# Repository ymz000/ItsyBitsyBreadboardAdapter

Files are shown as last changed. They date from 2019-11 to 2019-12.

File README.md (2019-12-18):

### _A stacking breadboard adapter for the ItsyBitsy M4 Express_

# ItsyBitsyBreadboardAdapter

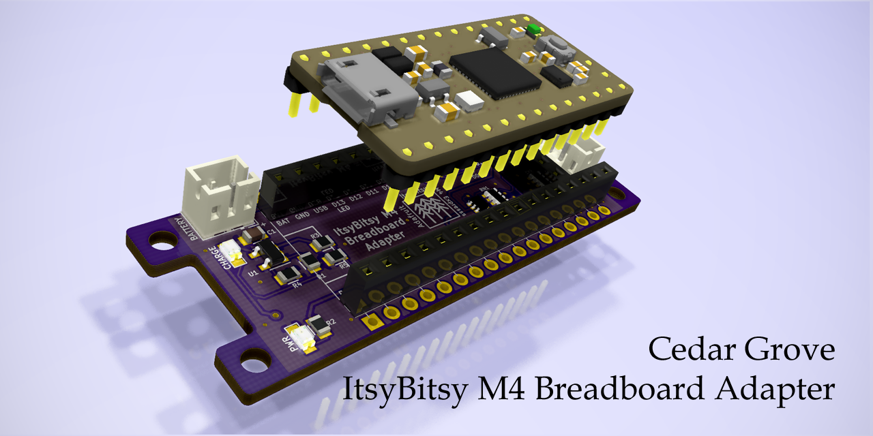
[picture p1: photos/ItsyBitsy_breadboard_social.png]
Image of Module


## Overview
The ItsyBitsy Breadboard Adapter is an Adafruit ItsyBitsy M4 Express-compatible piggyback module that converts the 3-sided pinout of the ItsyBitsy to dual in-line for use on typical solderless breadboards and soldered protoboards. The adapter was also designed with extra solderable pin connections and mounting ears for permanent installation.

Included is a level-shifted 4-pin JST STEMMA connector with jumper-selectable 5v or 3.3v power. The STEMMA interface can be configured to connect to the ItsyBitsy's UART (RX/TX) or I2C (SCL/SDA) signals. A 2-pin JST LiPo battery connection is on-board that supports charging (100mA charge rate), compatible with Adafruit's standard battery polarity.

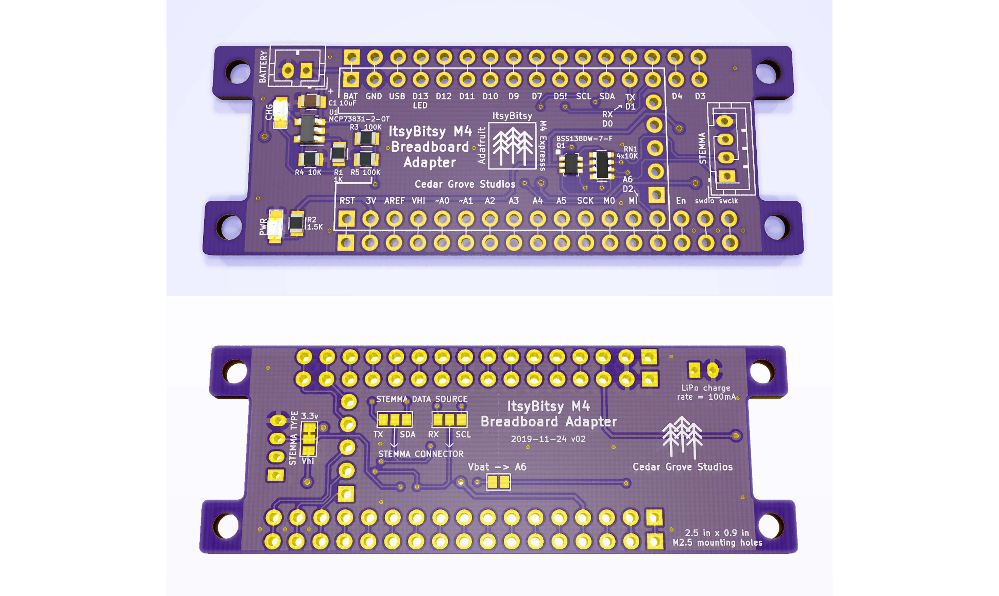
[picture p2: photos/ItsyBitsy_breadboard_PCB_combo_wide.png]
Image of PCB


OSH Park shared project:

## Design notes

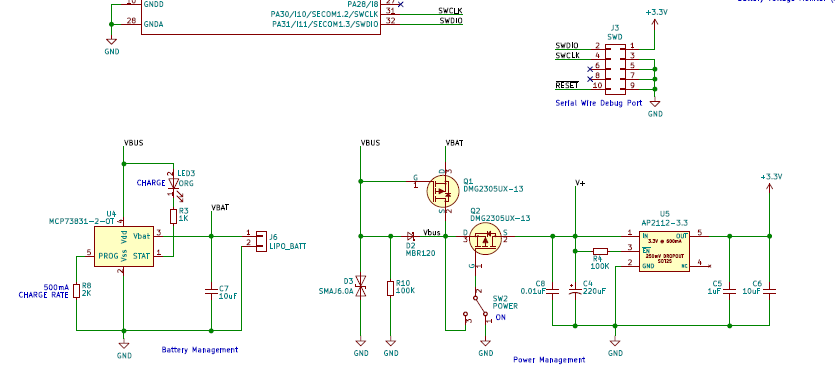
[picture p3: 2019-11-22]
photos/stringcar m0 pwr batt swd mgt.png

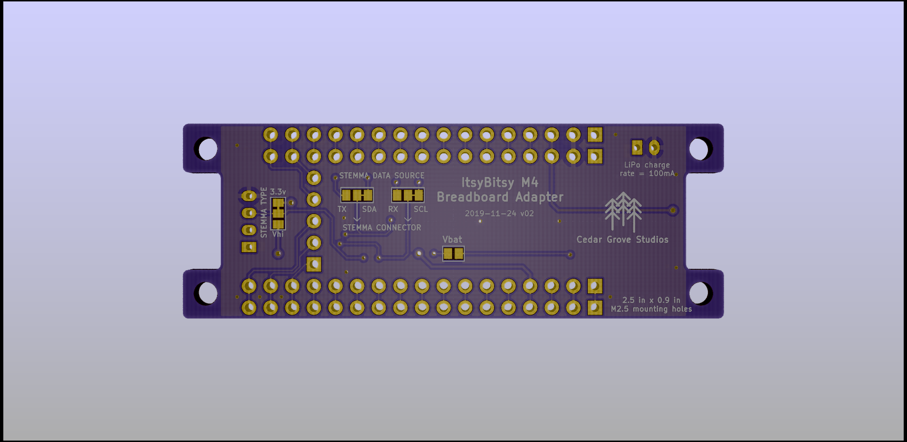
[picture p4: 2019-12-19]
photos/ItsyBitsy_breadboard_bot.png

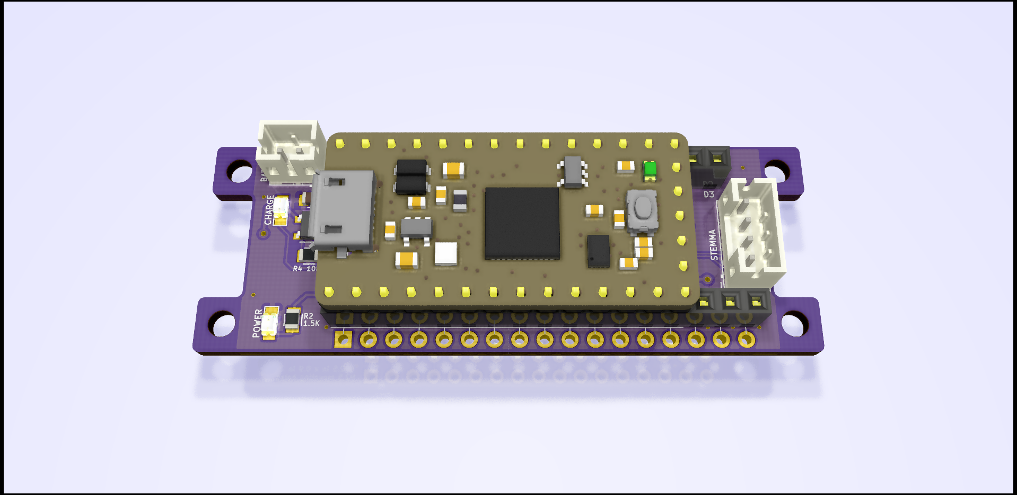
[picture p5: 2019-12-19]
photos/ItsyBitsy_breadboard_stacked.png

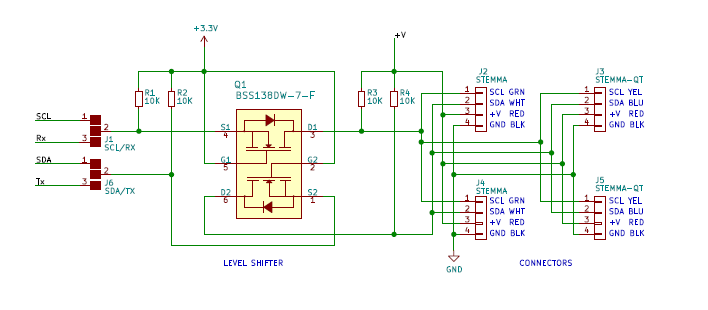
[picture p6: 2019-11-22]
photos/i2c buffer.png

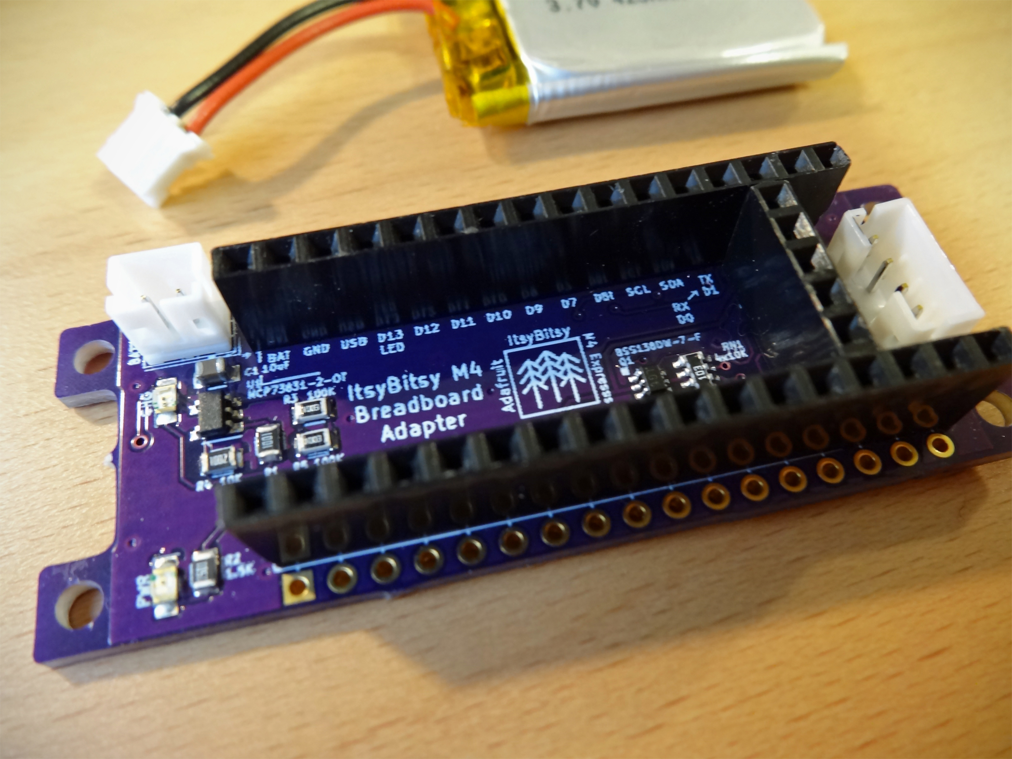
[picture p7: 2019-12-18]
photos/DSC05937a.jpg

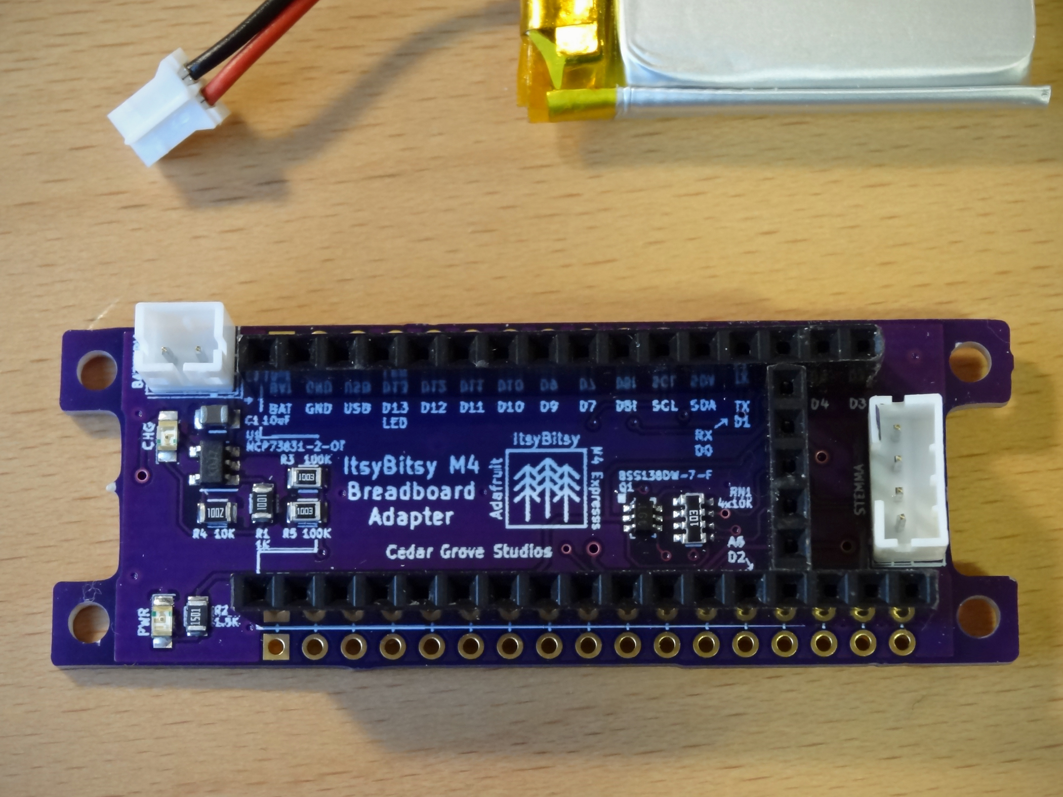
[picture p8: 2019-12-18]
photos/DSC05936a.jpg

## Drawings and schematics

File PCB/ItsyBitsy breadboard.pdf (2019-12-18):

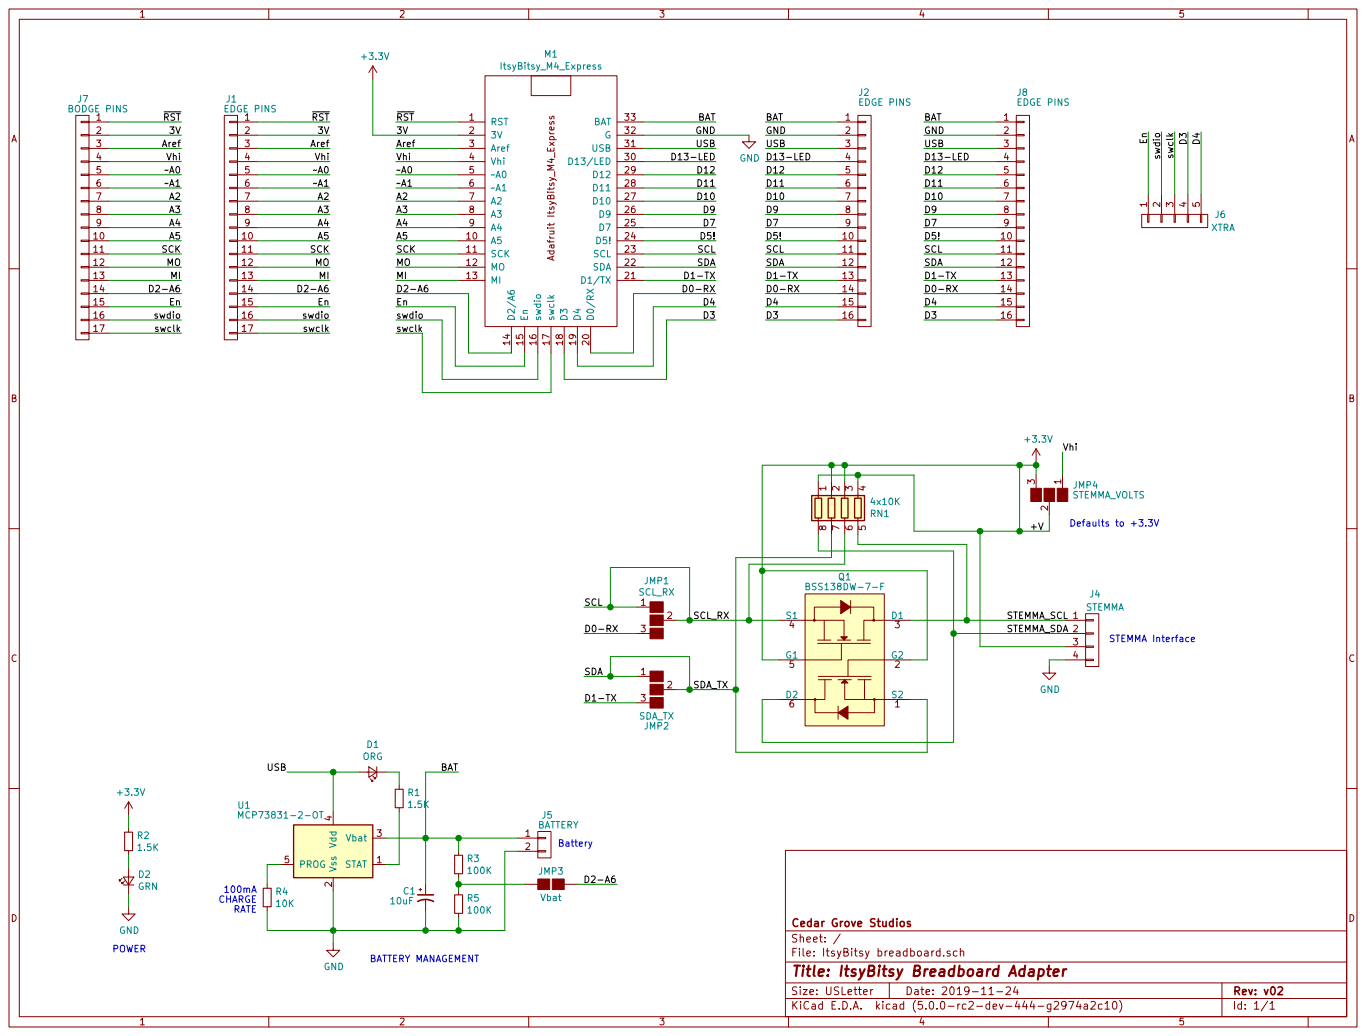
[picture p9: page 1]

File: ItsyBitsy breadboard.sch Sheet: / Cedar Grove Studios

Id: 1/1 Title: ItsyBitsy Breadboard Adapter

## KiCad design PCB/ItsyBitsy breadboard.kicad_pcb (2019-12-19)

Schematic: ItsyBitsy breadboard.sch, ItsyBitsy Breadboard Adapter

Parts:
C1: 10uF; C_0805
D1: ORG; LED_0805
D2: GRN; LED_0805
J1: EDGE PINS; Pin_Header_Straight_1x17_Pitch2.54mm_no_silk
J2, J8: EDGE PINS; Pin_Header_Straight_1x16_Pitch2.54mm_no_silk
J4: STEMMA; JST_PH_B4B-PH-K_04x2.00mm_Straight
J5: BATTERY; JST_PH_B2B-PH-K_02x2.00mm_Straight
J6: XTRA; Pin_Header_Straight_1x05_Pitch2.54mm_no_silk
J7: BODGE PINS; Pin_Header_Straight_1x17_Pitch2.54mm_no_silk
JMP1: SCL_RX; GS3
JMP2: SDA_TX; GS3
JMP3: Vbat; GS2
JMP4: STEMMA_VOLTS; GS3
M1: ItsyBitsy_M4_Express
Q1: BSS138DW-7-F; SOT-363; MPN BSS138DW-7-F; Digi-Key_PN BSS138DW-FDICT-ND
R1, R2: 1.5K; R_0805
R3, R5: 100K; R_0805
R4: 10K; R_0805
RN1: 4x10K; R_Array_Convex_4x0603
U1: MCP73831-2-OT; SOT-23-5

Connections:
+3V3: J1.2, J4.3, J7.2, JMP4.2, JMP4.3, Q1.2, Q1.5, R2.1, RN1.1, RN1.2, RN1.3, RN1.4
/A2: J1.7, J7.7
/A3: J1.8, J7.8
/A4: J1.9, J7.9
/A5: J1.10, J7.10
/Aref: J1.3, J7.3
/BAT: C1.1, J2.1, J5.1, J8.1, R3.1, U1.3 (Vbat)
/D0-RX: J2.14, J8.14, JMP1.3
/D1-TX: J2.13, J8.13, JMP2.3
/D2-A6: J1.14, J7.14, JMP3.1
/D3: J2.16, J6.4, J8.16
/D4: J2.15, J6.5, J8.15
/D5!: J2.10, J8.10
/D7: J2.9, J8.9
/D9: J2.8, J8.8
/D10: J2.7, J8.7
/D11: J2.6, J8.6
/D12: J2.5, J8.5
/D13-LED: J2.4, J8.4
/En: J1.15, J6.1, J7.15
/MI: J1.13, J7.13
/MO: J1.12, J7.12
/SCK: J1.11, J7.11
/SCL: J2.11, J8.11, JMP1.1, JMP1.2, Q1.4, RN1.6
/SDA: J2.12, J8.12, JMP2.1, JMP2.2, Q1.1, RN1.7
/STEMMA_SCL: J4.1, Q1.3, RN1.5
/STEMMA_SDA: J4.2, Q1.6, RN1.8
/USB: D1.2, J2.3, J8.3, U1.4 (Vdd)
/Vhi: J1.4, J7.4, JMP4.1
/swclk: J1.17, J6.3, J7.17
/swdio: J1.16, J6.2, J7.16
/~RST: J1.1, J7.1
/~~A0: J1.5, J7.5
/~~A1: J1.6, J7.6
GND: C1.2, D2.1, J2.2, J4.4, J5.2, J8.2, R4.2, R5.2, U1.2 (Vss)
unnamed: D1.1, R1.1
unnamed: D2.2, R2.2
unnamed: JMP3.2, R3.2, R5.1
unnamed: R1.2, U1.1 (STAT)
unnamed: R4.1, U1.5 (PROG)

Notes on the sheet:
STEMMA Interface
Battery
100mA CHARGE RATE
POWER
BATTERY MANAGEMENT
Defaults to +3.3V

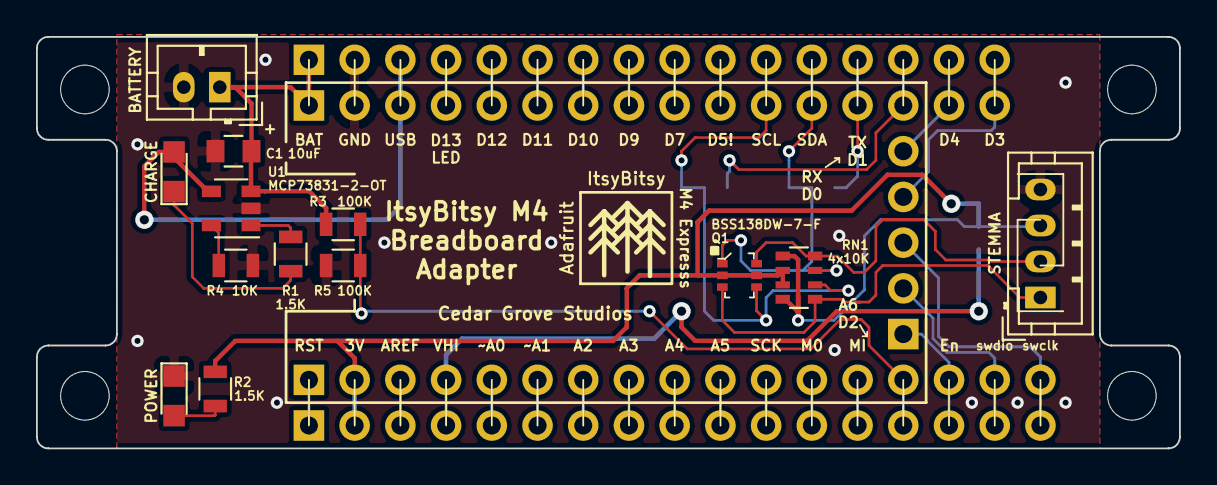
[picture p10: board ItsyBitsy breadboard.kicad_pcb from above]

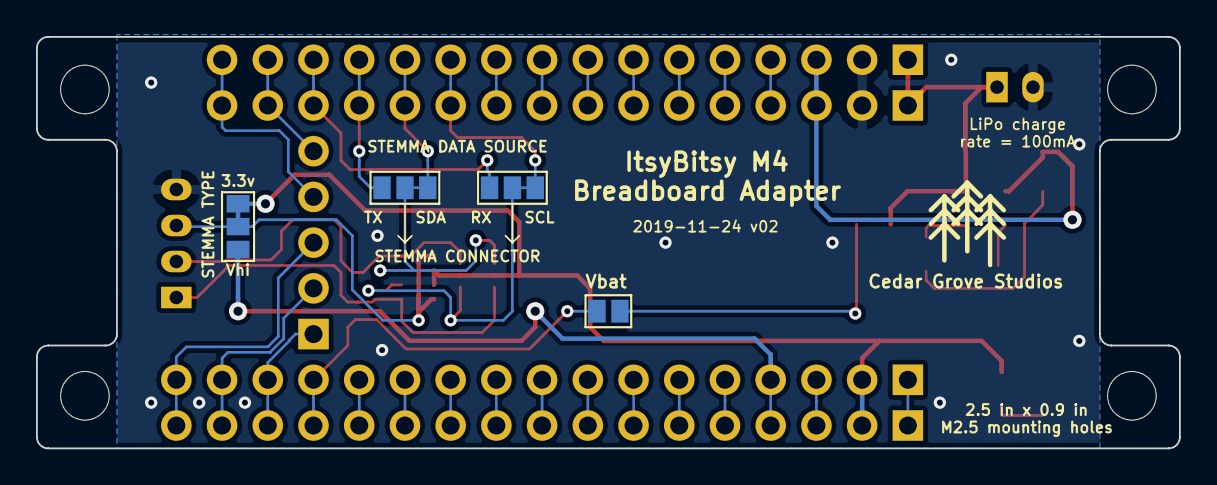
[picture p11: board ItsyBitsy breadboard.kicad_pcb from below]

Board: 2 copper layers, 63.5 x 22.9 mm, 22 parts (4 on the bottom side), 40 nets.

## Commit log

2019-04-28 Initial repository load
    [ItsyBitsy breadboad-B.Cu.gbl, ItsyBitsy breadboad-B.Mask.gbs, ItsyBitsy breadboad-B.Paste.gbp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]
2019-11-22 collect circuit ideas for next version
    [ItsyBitsy breadboard.sch]
2019-11-25 update with new design and photos
    [ItsyBitsy breadboad-B.Cu.gbl, ItsyBitsy breadboad-B.Mask.gbs, ItsyBitsy breadboad-B.Paste.gbp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]
2019-11-25 update footprint
    [ItsyBitsy breadboard.kicad_pcb]
2019-11-25 update design and layout
    [ItsyBitsy breadboard-B.Cu.gbl, ItsyBitsy breadboard-B.Mask.gbs, ItsyBitsy breadboard-B.Paste.gbp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]
2019-11-25 Update STEMMA type default
    [ItsyBitsy breadboard-B.Cu.gbl, ItsyBitsy breadboard-B.Mask.gbs, ItsyBitsy breadboard-B.Paste.gbp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]
2019-11-25 update circuit design
2019-11-25 update charging design
    [ItsyBitsy breadboard-B.Cu.gbl, ItsyBitsy breadboard-B.Mask.gbs, ItsyBitsy breadboard-B.Paste.gbp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]
2019-11-25 update renderings
    [ItsyBitsy breadboard-B.Cu.gbl, ItsyBitsy breadboard-B.Mask.gbs, ItsyBitsy breadboard-B.Paste.gbp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]
2019-12-18 add assembled and tested photos
2019-12-18 update charging LED resistor
    [ItsyBitsy breadboard-B.Cu.gbl, ItsyBitsy breadboard-B.Mask.gbs, ItsyBitsy breadboard-B.Paste.gbp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]
2019-12-18 add default Stemma jumpers
    [ItsyBitsy breadboard-B.Cu.gbl, ItsyBitsy breadboard-B.Mask.gbs, ItsyBitsy breadboard-B.Paste.gbp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]
2019-12-19 update PCB silkscreen
    [ItsyBitsy breadboard-B.Cu.gbl, ItsyBitsy breadboard-B.Mask.gbs, ItsyBitsy breadboard-B.Paste.gbp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]
